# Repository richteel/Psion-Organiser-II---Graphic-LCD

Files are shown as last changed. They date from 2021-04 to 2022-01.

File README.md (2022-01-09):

# Psion Organiser II - Graphic-LCD
Replacing internals of a Psion Organiser II to include a Graphic LCD

- MCP23017 & MCP23S17 Product Pages
 - <a href="https://www.microchip.com/wwwproducts/en/mcp23017">Microchip MCP23017</a>
 - <a href="https://www.microchip.com/wwwproducts/en/mcp23S17">Microchip MCP23S17</a>
 - <a href="https://www.adafruit.com/product/732">Adafruit MCP23017</a>
- MCP23017 & MCP23S17 Datasheets
 - <a href="https://ww1.microchip.com/downloads/en/DeviceDoc/20001952C.pdf">Microchip (2016)</a>
 - <a href="https://cdn-shop.adafruit.com/datasheets/mcp23017.pdf">Adafruit (Microchip 2007)</a>

There is not much here for this project and it has been a while since I worked on the project. I don't know when I will get back to it. I did see a really cool project today along these same lines using an OLED display. The project is on YouTube by user <a href="https://www.youtube.com/channel/UCNweFQHar6-JMdXFk-MrOtQ/videos">A Menadue</a>.

I may abandon this project and try to do what A Menadue is doing as he has been able to do a great deal more work on this and in my opinion done a far better job that I would. I have been debating on attempting to recreate what Psion did or doing something different to take advantage of additional I/O and the graphics display.

The first video of A Menadue's project is at <a href="https://youtu.be/v2YWStDrQIs">https://youtu.be/v2YWStDrQIs</a>.

<a href="https://richteel.github.io/Psion-Organiser-II---Graphic-LCD/">GitHub Pages</a> - Currently blank.

The display that I've used is a Crystalfontz LCD <a href="https://www.crystalfontz.com/product/cfag12232dyyhva-transflective-graphic-lcd-122x32">CFAG12232D-YYH-VA</a>. I also used an Arduino Micro for the microcontroller to run the code. I was planning on using a Raspberry Pi Zero W but with Raspberry Pi Pico/RP2040 and an ESP32 seem link a better option.

Here are some photos taken of the sample code running the display.
April's Fools Joke showing Psion II Organizer with Series 3 Icons

April's Fools Joke showing Psion II Organizer with Series 3 Icons

April's Fools Joke showing Psion II Organizer with Series 3 Icons

<a href="https://github.com/richteel/Psion-Organiser-II---Graphic-LCD/blob/main/Code/sketch_April_Fools/Facebook/Psion%20April%20Fools.mp4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">Video of source code running</a>

<video width="320" height="240" controls>
  <source src="https://github.com/richteel/Psion-Organiser-II---Graphic-LCD/blob/main/Code/sketch_April_Fools/Facebook/Psion%20April%20Fools.mp4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" type="video/mp4">
Your browser does not support the video tag.
</video>

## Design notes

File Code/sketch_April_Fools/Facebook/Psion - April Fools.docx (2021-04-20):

Now that it is spring, the yard sales have started. I was at a yard sale with my wife and came across a super rare item. The lady that I spoke to said that her father had worked at Psion in the ‘80s and ‘90s as an engineer and was able to keep some prototypes. She had a box of Psion stuff from her father she sold me for $50 bucks. It seemed like a great deal. When I got home, I was going through the items and found this unexpected gem. It looks like Psion was planning to produce a graphic Organiser in the same form factor as the Organiser II devices. To my surprise, it powered on when I applied power to it. Has anyone heard about this before?

Here are some images and a short video of it starting up. Unfortunately, nothing happens when I press the keys on the device. I will have to investigate later to see if I can get the keyboard to work.

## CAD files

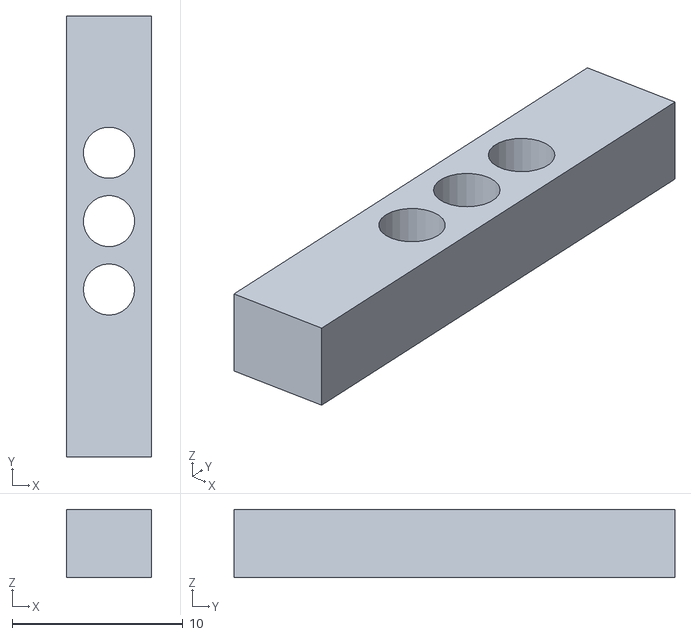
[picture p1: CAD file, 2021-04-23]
Case Parts/LED Shroud.stl
5.00 x 25.8 x 4.00

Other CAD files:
Case Parts/LED Shroud.skp

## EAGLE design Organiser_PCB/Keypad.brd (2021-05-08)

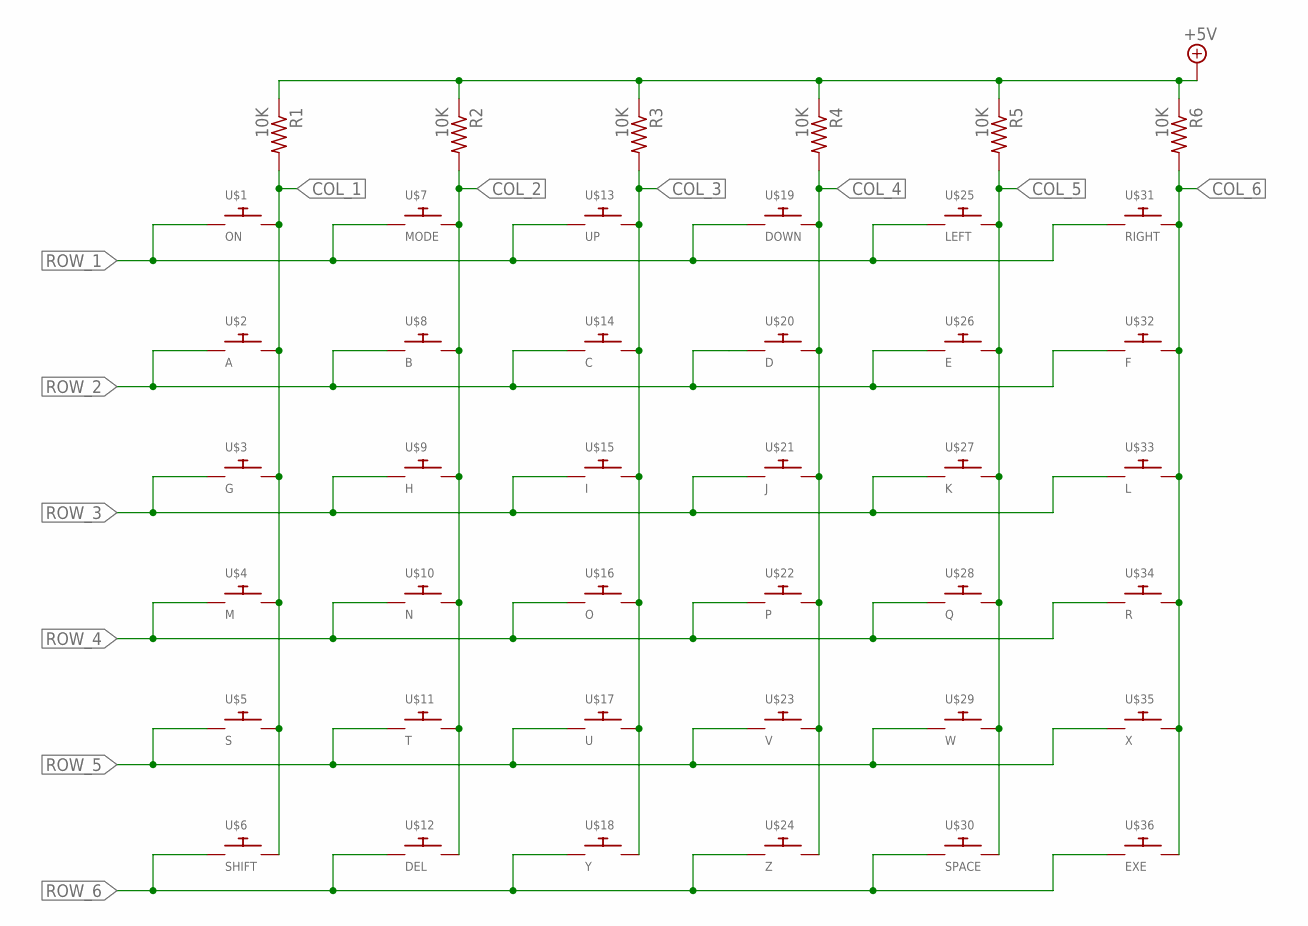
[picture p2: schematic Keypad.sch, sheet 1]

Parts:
R1, R2, R3, R4, R5, R6: 10K; M0805
U$1: ON; KEYPAD_RND
U$2: A; KEYPAD_RND
U$3: G; KEYPAD_RND
U$4: M; KEYPAD_RND
U$5: S; KEYPAD_RND
U$6: SHIFT; KEYPAD_RND
U$7: MODE; KEYPAD_RND
U$8: B; KEYPAD_RND
U$9: H; KEYPAD_RND
U$10: N; KEYPAD_RND
U$11: T; KEYPAD_RND
U$12: DEL; KEYPAD_RND
U$13: UP; KEYPAD_RND
U$14: C; KEYPAD_RND
U$15: I; KEYPAD_RND
U$16: O; KEYPAD_RND
U$17: U; KEYPAD_RND
U$18: Y; KEYPAD_RND
U$19: DOWN; KEYPAD_RND
U$20: D; KEYPAD_RND
U$21: J; KEYPAD_RND
U$22: P; KEYPAD_RND
U$23: V; KEYPAD_RND
U$24: Z; KEYPAD_RND
U$25: LEFT; KEYPAD_RND
U$26: E; KEYPAD_RND
U$27: K; KEYPAD_RND
U$28: Q; KEYPAD_RND
U$29: W; KEYPAD_RND
U$30: SPACE; KEYPAD_RND
U$31: RIGHT; KEYPAD_RND
U$32: F; KEYPAD_RND
U$33: L; KEYPAD_RND
U$34: R; KEYPAD_RND
U$35: X; KEYPAD_RND
U$36: EXE; KEYPAD_RND
U$40: TEELSYS_LOGO_ART_2BOTTOM; TEELSYS_LOGO_ART_BOTTOM_2

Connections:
+5V: R1.1, R2.1, R3.1, R4.1, R5.1, R6.1; also elsewhere on the board
COL_1: R1.2, U$1.P$2, U$2.P$2, U$3.P$2, U$4.P$2, U$5.P$2, U$6.P$2; also elsewhere on the board
COL_2: R2.2, U$7.P$2, U$8.P$2, U$9.P$2, U$10.P$2, U$11.P$2, U$12.P$2; also elsewhere on the board
COL_3: R3.2, U$13.P$2, U$14.P$2, U$15.P$2, U$16.P$2, U$17.P$2, U$18.P$2; also elsewhere on the board
COL_4: R4.2, U$19.P$2, U$20.P$2, U$21.P$2, U$22.P$2, U$23.P$2, U$24.P$2; also elsewhere on the board
COL_5: R5.2, U$25.P$2, U$26.P$2, U$27.P$2, U$28.P$2, U$29.P$2, U$30.P$2; also elsewhere on the board
COL_6: R6.2, U$31.P$2, U$32.P$2, U$33.P$2, U$34.P$2, U$35.P$2, U$36.P$2; also elsewhere on the board
ROW_1: U$1.P$1, U$7.P$1, U$13.P$1, U$19.P$1, U$25.P$1, U$31.P$1; also elsewhere on the board
ROW_2: U$2.P$1, U$8.P$1, U$14.P$1, U$20.P$1, U$26.P$1, U$32.P$1; also elsewhere on the board
ROW_3: U$3.P$1, U$9.P$1, U$15.P$1, U$21.P$1, U$27.P$1, U$33.P$1; also elsewhere on the board
ROW_4: U$4.P$1, U$10.P$1, U$16.P$1, U$22.P$1, U$28.P$1, U$34.P$1; also elsewhere on the board
ROW_5: U$5.P$1, U$11.P$1, U$17.P$1, U$23.P$1, U$29.P$1, U$35.P$1; also elsewhere on the board
ROW_6: U$6.P$1, U$12.P$1, U$18.P$1, U$24.P$1, U$30.P$1, U$36.P$1; also elsewhere on the board

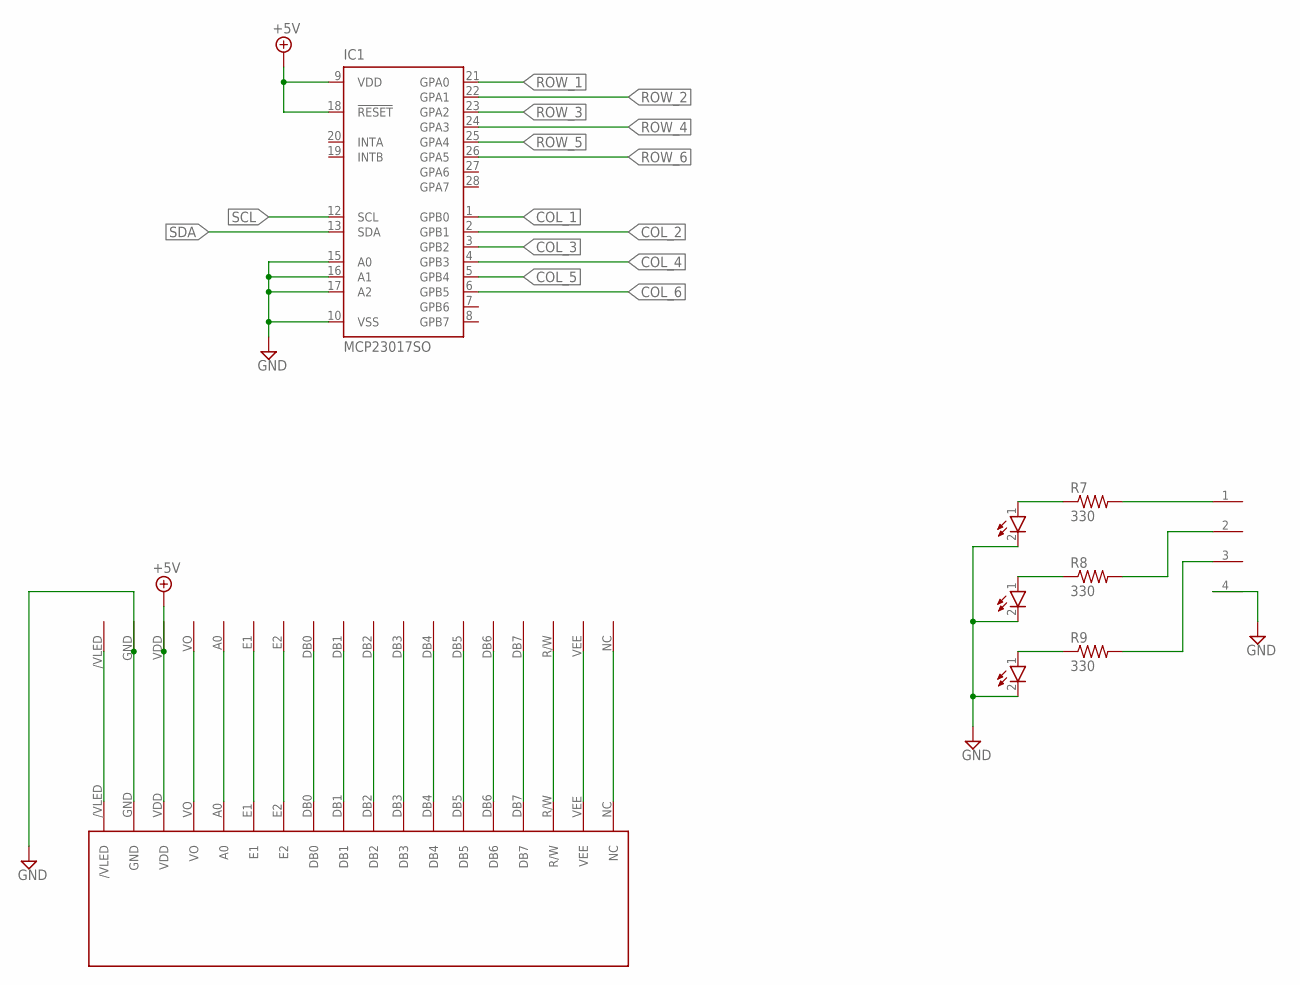
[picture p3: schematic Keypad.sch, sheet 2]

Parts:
IC1: MCP23017SO; SO28W
LED1: RED; HEADER-1X2
LED2: Green; HEADER-1X2
LED3: BLUE; HEADER-1X2
R7, R8, R9: 330; M0805
U$38: HEADER-1X18-LCD
U$39: HEADER-1X4
U$73: LCD_CFAL12832A022

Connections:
+5V: IC1.9 (VDD), IC1.18 (!RESET), U$38.VDD, U$73.VDD; also elsewhere on the board
/VLED: U$38./VLED, U$73./VLED
A0: U$38.A0, U$73.A0
COL_1: IC1.1 (GPB0); also elsewhere on the board
COL_2: IC1.2 (GPB1); also elsewhere on the board
COL_3: IC1.3 (GPB2); also elsewhere on the board
COL_4: IC1.4 (GPB3); also elsewhere on the board
COL_5: IC1.5 (GPB4); also elsewhere on the board
COL_6: IC1.6 (GPB5); also elsewhere on the board
DB0: U$38.DB0, U$73.DB0
DB1: U$38.DB1, U$73.DB1
DB2: U$38.DB2, U$73.DB2
DB3: U$38.DB3, U$73.DB3
DB4: U$38.DB4, U$73.DB4
DB5: U$38.DB5, U$73.DB5
DB6: U$38.DB6, U$73.DB6
DB7: U$38.DB7, U$73.DB7
E1: U$38.E1, U$73.E1
E2: U$38.E2, U$73.E2
GND: IC1.10 (VSS), IC1.15 (A0), IC1.16 (A1), IC1.17 (A2), LED1.2 (K), LED2.2 (K), LED3.2 (K), U$38.GND, U$39.4, U$73.GND
unnamed: LED3.1 (A), R9.1
unnamed: LED2.1 (A), R8.1
unnamed: LED1.1 (A), R7.1
unnamed: R9.2, U$39.3
unnamed: R8.2, U$39.2
unnamed: R7.2, U$39.1
NC: U$38.NC, U$73.NC
R/W: U$38.R/W, U$73.R/W
ROW_1: IC1.21 (GPA0); also elsewhere on the board
ROW_2: IC1.22 (GPA1); also elsewhere on the board
ROW_3: IC1.23 (GPA2); also elsewhere on the board
ROW_4: IC1.24 (GPA3); also elsewhere on the board
ROW_5: IC1.25 (GPA4); also elsewhere on the board
ROW_6: IC1.26 (GPA5); also elsewhere on the board
SCL: IC1.12 (SCL)
SDA: IC1.13 (SDA)
VEE: U$38.VEE, U$73.VEE
VO: U$38.VO, U$73.VO

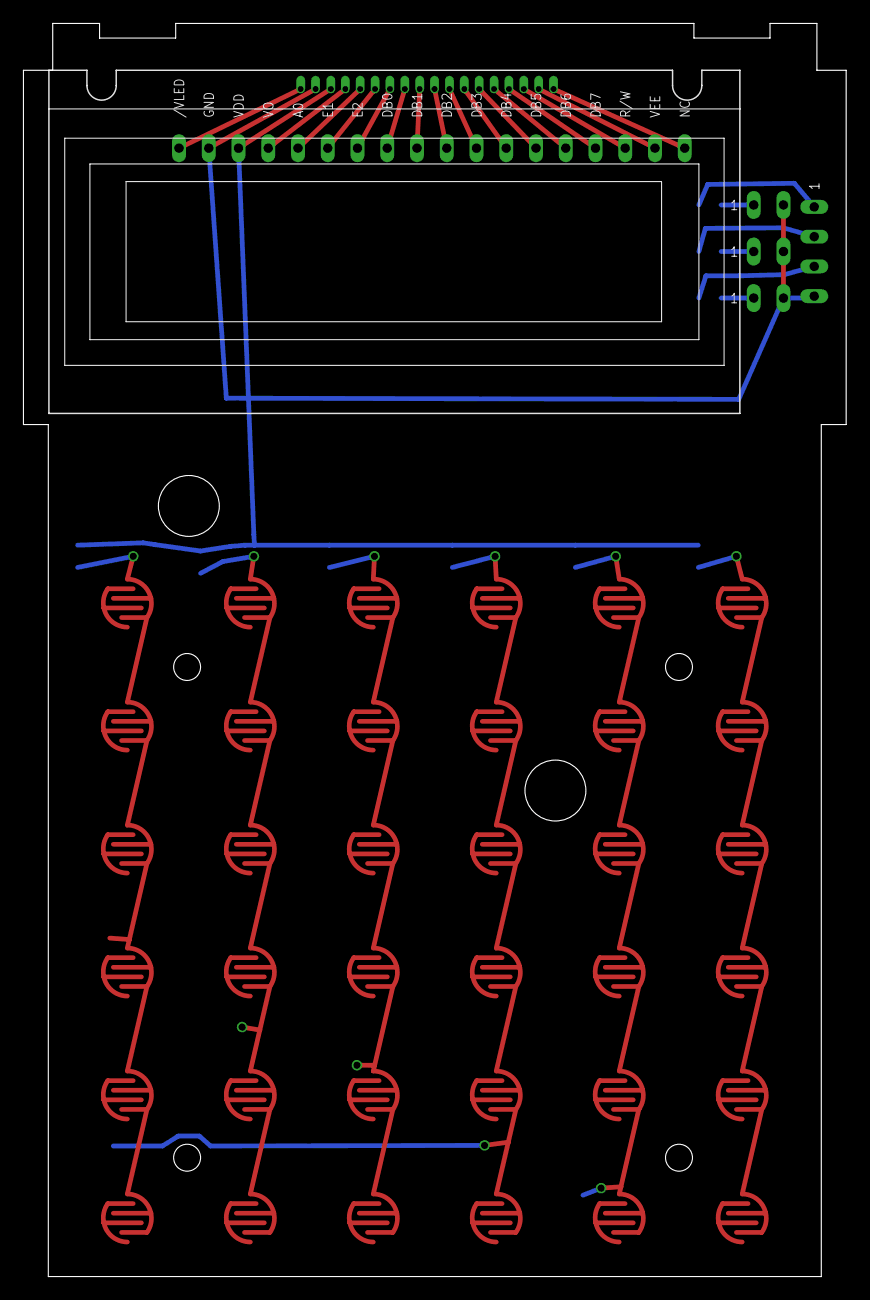
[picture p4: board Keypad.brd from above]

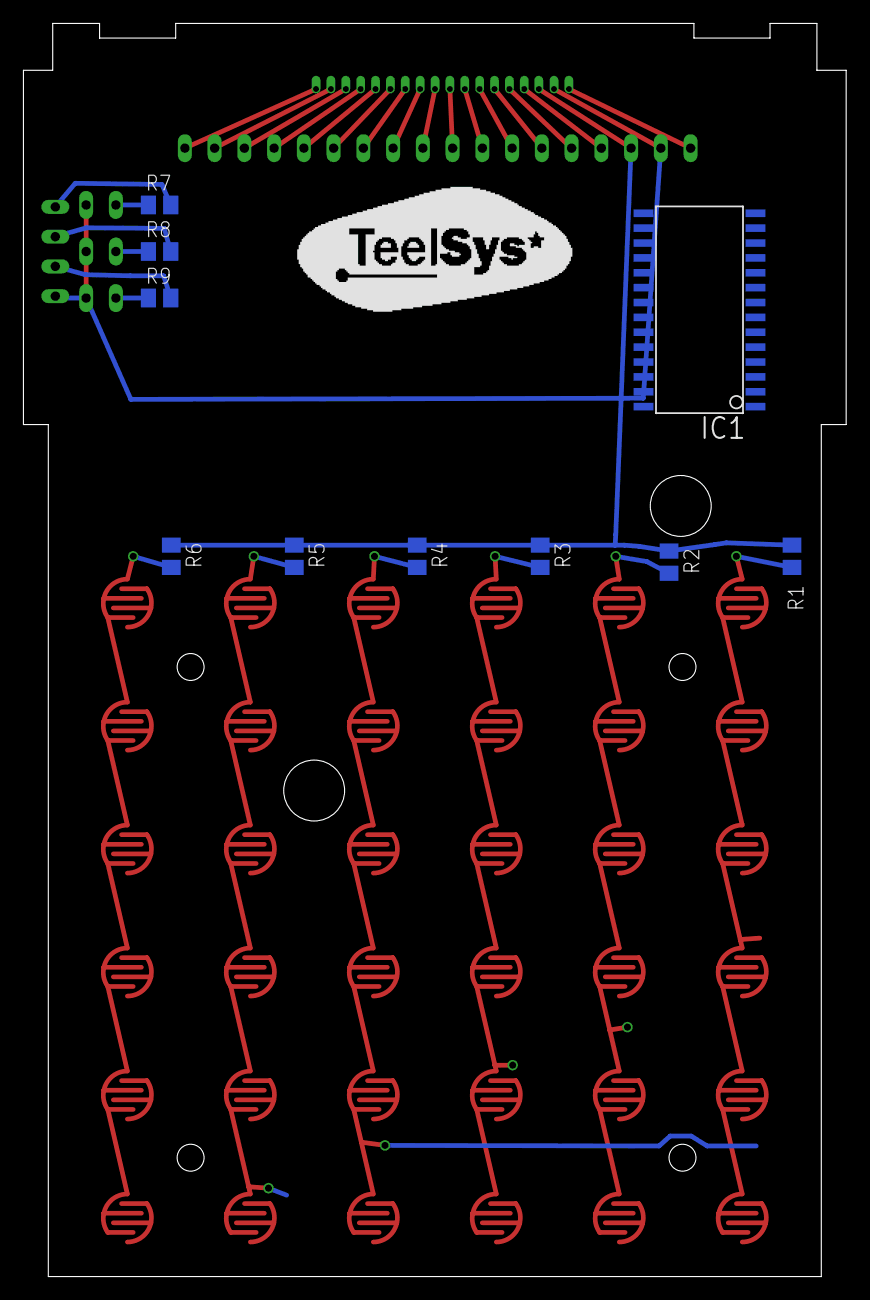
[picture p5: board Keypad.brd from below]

Board: 2 copper layers, 70.2 x 107.0 mm, 53 parts (10 on the bottom side), 36 nets.

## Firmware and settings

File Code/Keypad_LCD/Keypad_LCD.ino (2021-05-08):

#include <Wire.h>
#include "Adafruit_MCP23017.h"
#include "TeelSys_MCP23S17.h"
#include "TeelSys_I2C_Keypad.h"
#include "SED1520_122x32_SPI.h"

#define RED_PIN 1
#define YEL_PIN 0
#define GRN_PIN 9

const byte ROWS = 6;  // rows
const byte COLS = 6; // columns
//define the symbols on the buttons of the keypads
char keys[ROWS][COLS] = {
  {0x00, 0x01, 0x02, 0x03, 0x04, 0x05},
  {0x06, 0x07, 0x08, 0x09, 0x0A, 0x0B},
  {0x0C, 0x0D, 0x0E, 0x0F, 0x10, 0x11},
  {0x12, 0x13, 0x14, 0x15, 0x16, 0x17},
  {0x18, 0x19, 0x1A, 0x1B, 0x1C, 0x1D},
  {0x1E, 0x1F, 0x20, 0x21, 0x22, 0x23}
};

char keys_standard[ROWS][COLS] = {
  {0x00, 0x01, 0x1E, 0x1F, 0x1D, 0x1C},
  {'a', 'b', 'c', 'd', 'e', 'f'},
  {'g', 'h', 'i', 'j', 'k', 'l'},
  {'m', 'n', 'o', 'p', 'q', 'r'},
  {'s', 't', 'u', 'v', 'w', 'x'},
  {0x1E, 0x7F, 'y', 'z', ' ', 0x0D}
};

char keys_cap[ROWS][COLS] = {
  {0x00, 0x01, 0x1E, 0x1F, 0x1D, 0x1C},
  {'A', 'B', 'C', 'D', 'E', 'F'},
  {'G', 'H', 'I', 'J', 'K', 'L'},
  {'M', 'N', 'O', 'P', 'Q', 'R'},
  {'S', 'T', 'U', 'V', 'W', 'X'},
  {0x1E, 0x08, 'Y', 'Z', ' ', 0x0D}
};

char keys_num[ROWS][COLS] = {
  {0x00, 0x01, 0x1E, 0x1F, 0x1D, 0x1C},
  {'<', '>', '(', ')', '%', '/'},
  {'=', '"', '7', '8', '9', '*'},
  {',', '$', '4', '5', '6', '-'},
  {';', ':', '1', '2', '3', '+'},
  {0x1E, 0x7F, '0', '.', ' ', 0x0D}
};

char keys_special[ROWS][COLS] = {
  {0x00, 0x01, 0x1E, 0x1F, 0x1D, 0x1C},
  {'[', ']', '{', '}', '|', '\\'},
  {'~', '\'', '&', '*', '(', '?'},
  {'`', 0x9C, '$', '%', '^', 0x09},
  {';', ':', '!', '@', '#', 0x0A},
  {0x1E, 0x7F, ')', '.', ' ', 0x0D}
};

//Inputs/outputs
byte rowPins[ROWS] = {15, 13, 11, 2, 4, 6};  //connect to the row pinouts of the keypad
byte colPins[COLS] = {14, 12, 10, 3, 5, 7};  //connect to the column pinouts of the keypad

//Variables
bool SHIFT = false;
bool CAP_LOCK = false;
bool NUM_LOCK = false;

//---------- LCD ----------
#define BL_PIN 6  // Backlight
//------ LCD MCP23S17 -----
#define SS_PIN 17  // ChipSelect (SS)

//initialize an instance of class MCP23017
Adafruit_MCP23017 mcp0;
TeelSys_MCP23S17 mcp1;
//initialize an instance of class NewKeypad
TeelSys_I2C_Keypad customKeypad = TeelSys_I2C_Keypad( makeKeymap(keys), rowPins, colPins, ROWS, COLS, &mcp0);
SED1520_122x32_SPI lcd = SED1520_122x32_SPI(&mcp1);

void setup() {
  unsigned long startMillis = millis();
  Serial.begin(115200);           //If you change the speed here, the receiver Arduino will also need to change the speed.
  mcp0.begin();
  customKeypad.begin();

  mcp0.pinMode(RED_PIN, OUTPUT);
  mcp0.pinMode(YEL_PIN, OUTPUT);
  mcp0.pinMode(GRN_PIN, OUTPUT);

  mcp0.digitalWrite(RED_PIN, LOW);
  mcp0.digitalWrite(YEL_PIN, LOW);
  mcp0.digitalWrite(GRN_PIN, LOW);

  mcp1.begin(0, SS_PIN);
  mcp1.pinMode(BL_PIN, OUTPUT);
  mcp1.digitalWrite(BL_PIN, LOW);


  lcd.begin();
  
  mcp0.digitalWrite(GRN_PIN, HIGH);
  unsigned long endMillis = millis();

  lcd.GoTo(2, 0);
  lcd.WriteString("Hello World");
  
  char s[32];
  // https://cpp4arduino.com/2020/02/07/how-to-format-strings-without-the-string-class.html
  snprintf(s, sizeof(s), "time = %u ms", endMillis - startMillis);
  lcd.GoTo(2, 1);
  lcd.WriteString(s);
  
  lcd.GoTo(2, 2);
  lcd.WriteString("Line 3");
  
  lcd.GoTo(2, 3);
  lcd.WriteString("Line 4");

  lcd.Rectangle(0, 0, 122, 32);
  
  lcd.Circle(110, 10, 5);
  
  lcd.Line(110, 10, 45, 22);
  
  lcd.Circle(45, 22, 5);
}

void loop() {
  ////////////////////////////////////////////////////////////
  ///////Now detect when a keyboard button was pressed/////////
  ////////////////////////////////////////////////////////////
  customKeypad.tick();                      //Create the rows pulses

  while (customKeypad.available()) {        //If a new push button was detected...
    keypadEvent e = customKeypad.read();    //Get what character was pressed

    /**********************************************************/
    /***                 Check Modifier Keys                ***/
    /**********************************************************/
    if (e.bit.KEY == 0x1E) { // Shift Key
      SHIFT = e.bit.EVENT == KEY_JUST_PRESSED;
      continue;
    }

    if (e.bit.EVENT != KEY_JUST_PRESSED) {
      continue;
    }

    if (SHIFT && e.bit.KEY == 0x02) { // Cap Lock Key
      CAP_LOCK = !CAP_LOCK;
      mcp0.digitalWrite(RED_PIN, CAP_LOCK);
      continue;
    }

    if (SHIFT && e.bit.KEY == 0x03) { // Num Lock Key
      NUM_LOCK = !NUM_LOCK;
      mcp0.digitalWrite(YEL_PIN, NUM_LOCK);
      continue;
    }

    byte row = e.bit.KEY / 6;
    byte col = e.bit.KEY % 6;
    byte state = 0;
    /*
       state = 0 keys_standard
       state = 1 keys_cap
       state = 2 keys_num
       state = 3 keys_special
       state = 4 keys_special2
    */

    if (CAP_LOCK && NUM_LOCK) {
      if (SHIFT)
        state = 4;
      else
        state = 3;
    }
    else if (NUM_LOCK) {
      if (SHIFT)
        state = 0;
      else
        state = 2;
    }
    else if (CAP_LOCK) {
      if (SHIFT)
        state = 0;
      else
        state = 1;
    }
    else {
      if (SHIFT)
        state = 1;
      else
        state = 0;
    }

    char key = 0x00;

    switch (state) {
      case 4:
      case 3:
        key = keys_special[row][col];
        break;
      case 2:
        key = keys_num[row][col];
        break;
      case 1:
        key = keys_cap[row][col];
        break;
      default:
        key = keys_standard[row][col];
        break;
    }

    //Serial.print("row = "); Serial.print(row); Serial.print(" col = "); Serial.println(col);
    if (key == 0x00)
      mcp1.digitalWrite(BL_PIN, !mcp1.digitalRead(BL_PIN));
    else if (key == 0x0D)
      Serial.println();
    else
      Serial.print((char)key);
  }
  delay(5); //Small delay between each loop
}

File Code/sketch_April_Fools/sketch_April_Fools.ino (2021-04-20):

// SOURCE: https://www.htlinux.com/esp8266-json-weather-display/

#include <Arduino.h>
#include <U8g2lib.h>
#ifdef U8X8_HAVE_HW_SPI
#include <SPI.h>
#endif
#ifdef U8X8_HAVE_HW_I2C
#include <Wire.h>
#endif
#include "logo.h"
#include "menu.h"

U8G2_SED1520_122X32_F u8g2(U8G2_R0, 8, 9, 10, 11, 4, 5, 6, 7, /*dc=*/ A0, /*e1=*/ A3, /*e2=*/ A2, /* reset=*/  A4);   // Set R/W to low!
bool pcSerialConnected = true;

int state = 0;
const int delayMs = 2000;

void u8g2Print(const char *s, u8g2_uint_t line) {
  u8g2_uint_t y = (12 * line);
  if (line > 1) {
    y += 2;
  }
  u8g2.setCursor(0, y);
  u8g2.setFont(u8g2_font_unifont_t_latin); //first font
  u8g2.print(s);
}

void setup()
{
  u8g2.begin();
  u8g2.enableUTF8Print();
  u8g2.setFontDirection(0);

  //  u8g2.clearBuffer();
  //  u8g2Print("Booting", 1);
  //  u8g2.sendBuffer();

  Serial.begin(115200);   // PC for debuging

  /****** BEGIN: Serial Connection to PC ******/
  // Wait for PC Serial to connect (Typically < 300ms)
  unsigned long startMillis = millis();
  unsigned long endMillis = millis();
  while (!Serial) {
    endMillis = millis();
    if (endMillis - startMillis >= 1000) {
      pcSerialConnected = false;
      break;
    }
  }
  if (pcSerialConnected) {
    Serial.print("Time of Serial 0 = "); Serial.print(endMillis - startMillis); Serial.println(" ms");
  }
  /****** END: Serial Connection to PC ******/

  state = 0;
}

void loop() {
  state++;
  delay(delayMs);

  switch (state) {
    case 1:
      u8g2.clearBuffer();
      u8g2Print("  Organiser G", 1);
      u8g2Print("  ©Psion 1989", 2); // © Copyright Psion PLC 1989
      u8g2.sendBuffer();
      delay(delayMs);
      break;
    case 2:
      u8g2.clearBuffer();
      u8g2.firstPage();
      do {
        u8g2.drawXBMP( 0, 0, Psion_logo_122x32_20bw_width, Psion_logo_122x32_20bw_height, Psion_logo_122x32_20bw_bits);
      } while ( u8g2.nextPage() );
      u8g2.sendBuffer();
      delay(delayMs);
      break;
    case 3:
      u8g2.clearBuffer();
      u8g2.firstPage();
      do {
        u8g2.drawXBMP( 0, 0, Menu_width, Menu_height, Menu_bits);
      } while ( u8g2.nextPage() );
      u8g2.sendBuffer();
      break;
    default:
      delay(delayMs);
      state = state - 1;
      break;
  }

}

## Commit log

2021-04-13 Initial PCB Design
    [Keypad.brd, Keypad.sch]
2021-04-17 Adding Arduino code for the keyboard This code uses port operations on the MCP23017.
2021-04-18 Another keyboard test using the MCP23017 by pin rather than by port and including 3 LEDs
2021-04-20 Modified the code to work with the MCP23017 wired in straight rather than by port and added second MCP23017 for display. (Only backlight in use)
2021-04-23 Added LED Shroud 3D Print files
    [LED Shroud.skp, LED Shroud.stl]
2021-05-08 Changed LCD to use MCP23S17 with SPI interface Reduced example execution time to draw on LCD from 4 seconds down to 251 ms (I2C to SPI)
    [Keypad.brd, Keypad.sch]
2022-01-09 Just capturing changes that were made in the past in preparation with merging to main
    [Calc.xlsx]
